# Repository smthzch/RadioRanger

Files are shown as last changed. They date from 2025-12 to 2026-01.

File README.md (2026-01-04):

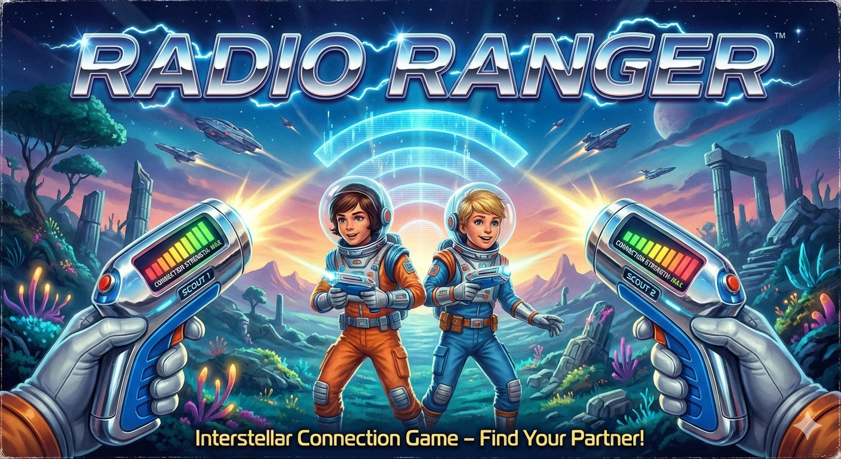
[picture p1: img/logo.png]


# Radio Ranger

Radio Ranger is a proximity sensing device. The LED meter increases in proportion to how close the two devices are to one another.

After the devices are turned on they will begin searching (single red light sweeping).
When one device discovers the other, it will display how close it is to the other device:

Far ← | Red | Yellow | Green | → Close

## Games

    • Blood Hound
        ◦ Hide one device and search with it with the other
    • Radio Tag
        ◦ Tag if green
    • Marco Polo
    • Use your imagination

## Battery Charge

Flashing indicates battery level 
    • No Flash = Charged
    • Slow Flash = Battery Low
    • Fast Flash = Charge Immediately

To charge plug in a usb-c cable to a standard 5v receptacle. 
The device must be turned ON in order to charge.

## Parts

- [XIAO ESP32C3](https://wiki.seeedstudio.com/XIAO_ESP32C3_Getting_Started/)
- [Adafruit LEDBAR](https://www.adafruit.com/product/1721)
- switch/battery

## XIAO ESP32C3 PINOUT

```
BATT(+/-)-|A0  USB  5V|-
         -|D1      GND|-LED(G)
         -|D2      3V3|-LED(VCC)
         -|D3      D10|-
LED(SDA) -|D4       D9|-
LED(SCL) -|D5       D8|-
         -|D6       D7|-
```

Pin A0 is connected to the positive and negative battery pads via 220K resistors for the battery voltage reading.
The battery is connected to the ESP32 battery pads via the switch.



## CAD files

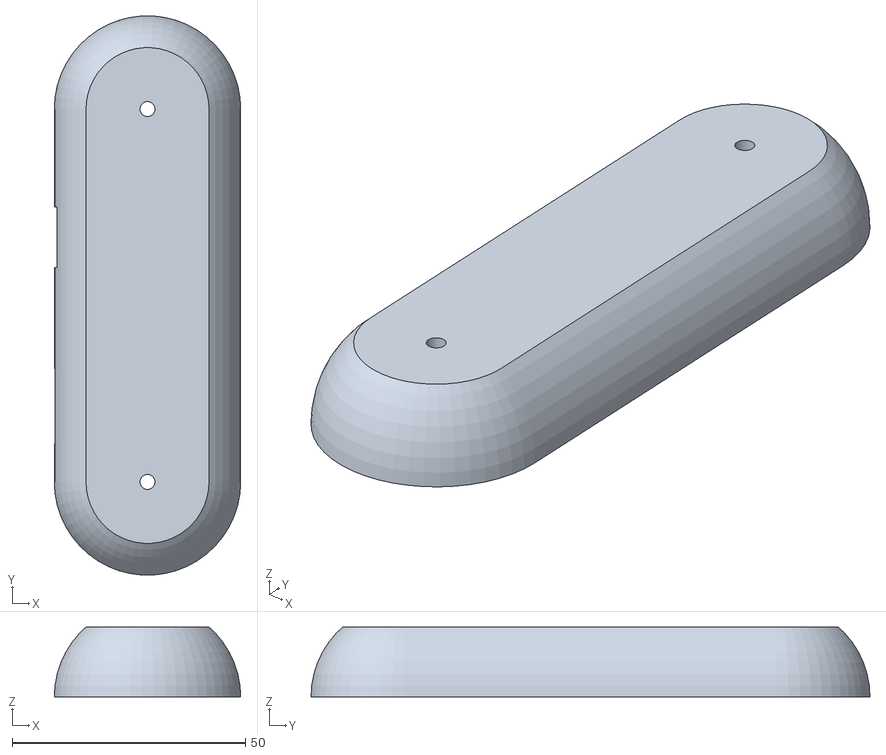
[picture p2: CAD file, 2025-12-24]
scad/radioranger_mini_top.stl
40.0 x 119.9 x 15.0

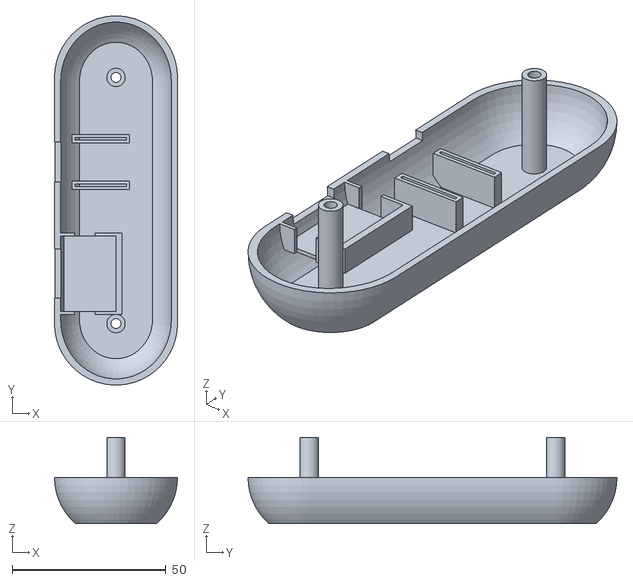
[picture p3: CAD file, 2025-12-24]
scad/radioranger_mini_bottom.stl
40.0 x 119.9 x 28.0

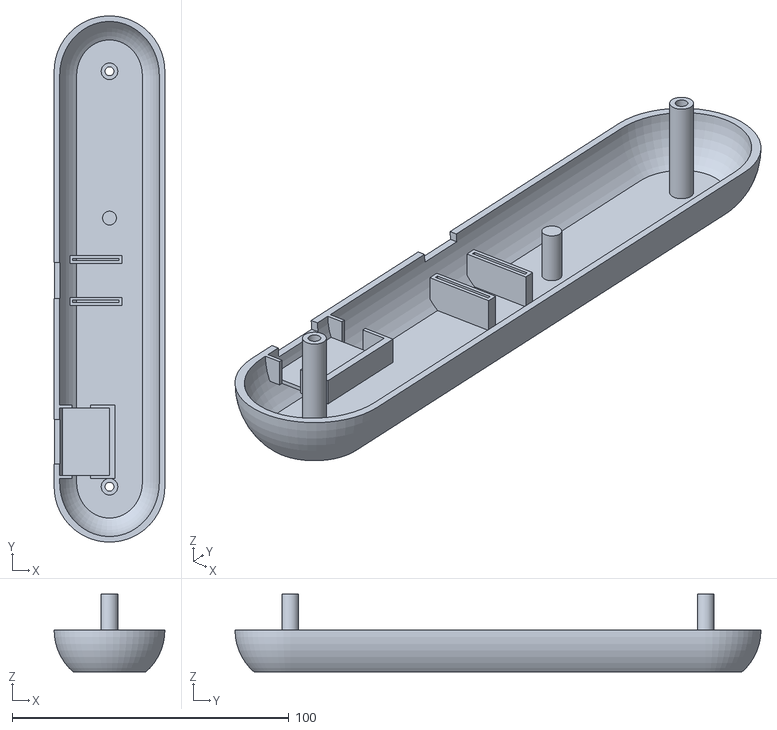
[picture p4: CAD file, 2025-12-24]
scad/radioranger_bottom.stl
40.0 x 189.9 x 28.0

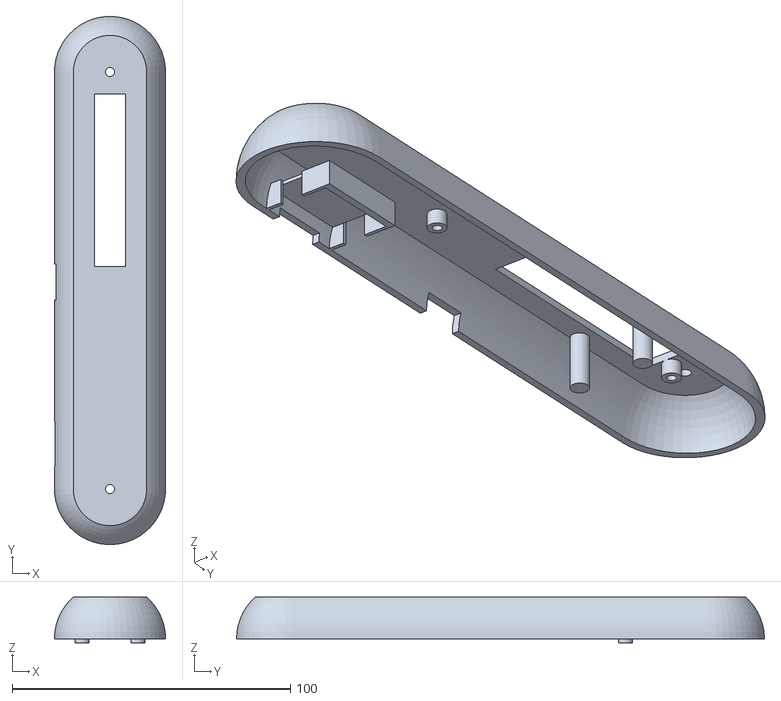
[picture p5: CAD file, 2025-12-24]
scad/radioranger_top.stl
40.0 x 189.9 x 16.5

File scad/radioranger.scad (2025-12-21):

$fn=50;



// screen hole
screen_l=62;
screen_w=11;
// switch holder
switch_l=26.5;
switch_d=20;
switch_h=13.5;
switch_t=1;
// enclosure
length=150; //150 //40
width=40;
wall_thickness=4;

//  ESP32 holder
module pinhole(w, d, h, o, do){
    difference(){
        translate([-o/2, -o/2, 0]) cube([w+o, d+do+o, h]);
        cube([w, d + do, h]);
    };
};

module esp_holder(){
    w=16.8;
    d=0.65;
    h=9;
    o=2;
    do = 0.2;
    
    pinhole(w, d, h, o, do);
    translate([0, 15.78 - d, 0]) pinhole(w, d, h, o, do);
}

module switch(){
    difference(){
        // switch body
        cube([switch_d, switch_l, switch_h]);
        // hollow
        translate([0, switch_t, switch_t])
        cube([
            switch_d-2*switch_t, 
            switch_l-2*switch_t, 
            switch_h-2*switch_t
        ]);
        // wire holes
        translate([switch_h/3, 0, 0])
        cube([switch_d/3, 1, switch_h]);
        // wire holes
        translate([switch_h/3, switch_l-switch_t, 0])
        cube([switch_d/3, 1, switch_h]);
    }
}

// enclosure
module shell(){   
    r=width/2;
    difference(){
        //main body
        union(){
            //center mass
            rotate([-90,0,0])
            cylinder(h=length,r=r);
            // end lobe 1
            sphere(r);
            // end lobe 2
            translate([0, length, 0])
            sphere(r);
        }
        // cutoff top
        translate([-r, -r, r - r/4])
        cube([2*r, length+2*r, 2*r]);
        // cutoff bottom
        translate([-r, -r, -3*r + r/4])
        cube([2*r, length+2*r, 2*r]);
    }
}

module hollow_shell(){
    difference(){
        // scale from origin so need to translate everything to be centered
        translate([0,length/2,0]) // return to original position
        difference(){
            translate([0, -length/2, 0]) // center it
            shell();
            //hollow it
            scale([
                1 - (wall_thickness / width), 
                1 - (wall_thickness / (length+width)), 
                1 - (wall_thickness / (3*width/4))
            ])
            translate([0, -length/2, 0]) // center it before scale
            shell();
        }
        // mounting hole
        translate([0, 0, -width/2])
        cylinder(h=width, d=3.2);
        // mounting hole
        translate([0, length, -width/2])
        cylinder(h=width, d=3.2);       
    }
    // internal components
    // switch
    translate([-width/2+switch_t+wall_thickness/2-1, 3, -switch_h/2])
    switch();
    //esp holder
    translate([-width/3, switch_l + 40, -width/3])
    esp_holder();
}

module enclosure(section){
    if(section=="top"){
        difference(){
            //shell
            hollow_shell();
            //remove bottom
            translate([-width/2, -width/2, -width])
            cube([width, length+width, width]);
            // screen hole
            translate([
                -screen_w/2, 
                length - screen_l - 3 - 5, 
                width/2 - width/8 -wall_thickness
            ])
            cube([screen_w, screen_l, wall_thickness]);
            // switch hole
            hole_l=16;
            hole_h=5;
            translate([-width/2, 26.5/2 - hole_l/2 + 3, -hole_h/2])
            cube([wall_thickness, hole_l, hole_h]);
            // usb hole
            translate([-width/2,switch_l+40+1.5,0])
            cube([wall_thickness, 13, 5]);
        }
        // screen mounting holes
        translate([0, length-3-2.5, 3*width/8-wall_thickness/2-4])
        difference(){
            cylinder(h=4, d=5);
            cylinder(h=4, d=2.5);
        }
        // screen mounting holes
        translate([0, length-3-2.5-95.25, 3*width/8-wall_thickness/2-4])
        difference(){
            cylinder(h=4, d=5);
            cylinder(h=4, d=2.5);
        }
        // battery holder
        buf=1.5;
        translate([10,120,-buf])
        cylinder(h=(3*width/8-wall_thickness/2)+buf, d=5);
        // battery holder
        translate([-10,120,-buf])
        cylinder(h=(3*width/8-wall_thickness/2)+buf, d=5);
    }if(section=="bottom"){
        difference(){
            //shell
            hollow_shell();
            //remove top
            translate([-width/2, -width/2, 0])
            cube([width, length+width, width]);
            // switch hole
            hole_l=16;
            hole_h=5;
            translate([-width/2, 26.5/2 - hole_l/2 + 3, -hole_h/2])
            cube([wall_thickness, hole_l, hole_h]);
            // usb hole
            translate([-width/2,switch_l+40+1.5,-2.2])
            cube([wall_thickness, 13, 2.2]);
        }
        // add mounting holes
        //mounting hole 1
        translate([0, 0, -3*width/8 + wall_thickness/2])
        difference(){
            cylinder(h=3*width/4 - wall_thickness, d=6);
            cylinder(h=3*width/4 - wall_thickness, d=3.2);
        }
        //mounting hole 2
        translate([0, length, -3*width/8 + wall_thickness/2])
        difference(){
            cylinder(h=3*width/4 - wall_thickness, d=6);
            cylinder(h=3*width/4 - wall_thickness, d=3.2);
        }
        // battery holder
        buf=1.5;
        translate([0,length-50-3,-3*width/8+wall_thickness/2])
        cylinder(h=(3*width/8-wall_thickness/2), d=5);
    }
}
section="bottom";
enclosure(section=section);
//enclosure(section="top");

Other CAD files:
scad/radioranger_mini.scad

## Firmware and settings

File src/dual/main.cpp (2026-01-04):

/* 
===========================================================
            Radio Ranger

This device connects to an equivalent device via bluetooth,
reads the signal strength and updates a LED bar visualizing
the relative strength.
===========================================================
            Pin Layout

BATT(+/-)-|A0  USB  5V|-
         -|D1      GND|-LED(G)
         -|D2      3V3|-LED(VCC)
         -|D3      D10|-
LED(SDA) -|D4       D9|-
LED(SCL) -|D5       D8|-
         -|D6       D7|-
*/

#if defined(RADIO)
  const char* MY_DEVICE_NAME = "RADIO";
  static const char* OTHER_DEVICE_MAC = "40:4c:ca:3c:f1:2a";
#elif defined(RANGER)
  const char* MY_DEVICE_NAME = "RANGER";
  static const char* OTHER_DEVICE_MAC = "94:a9:90:69:e6:12";
#else
  #error "Please define RADIO or RANGER in build flags or at top of sketch"
#endif

#include <BLEDevice.h>
#include <BLEScan.h>
#include <BLEAdvertisedDevice.h>
#include "Adafruit_LEDBackpack.h"
#include "battery.h"
#include "ledbar.h"

Adafruit_24bargraph  bar = Adafruit_24bargraph();

static BLEAddress targetAddr(OTHER_DEVICE_MAC);

BLEScan* pBLEScan = nullptr;
unsigned long previousMillis = 0;
const long interval = 500;  // Scan + update every 1.1 seconds
int no_contact = 1;
float min_rssi = -100;
float smooth_rssi = min_rssi;
float alpha = 0.2;


class MyAdvertisedDeviceCallbacks : public BLEAdvertisedDeviceCallbacks {
  void onResult(BLEAdvertisedDevice advertisedDevice) {
    if (advertisedDevice.getAddress().equals(targetAddr)) {
      smooth_rssi = alpha * (float)advertisedDevice.getRSSI() + (1 - alpha)* smooth_rssi;
      no_contact = 0;
    }
  }
};

// Dummy callback for asynchronous scanning
void onScanComplete(BLEScanResults results) {}

void setup() {
  Wire.setClock(100000);
  initBar(bar);

  pinMode(A0, INPUT); // ADC for battery voltage
  Serial.begin(9600);
  delay(1500);  // For XIAO USB CDC

  // BLE init
  BLEDevice::init(MY_DEVICE_NAME);

  // Start advertising (peripheral mode)
  BLEAdvertising* pAdvertising = BLEDevice::getAdvertising();
  pAdvertising->setScanResponse(true);
  pAdvertising->setMinPreferred(0x06);  // Helps with compatibility
  pAdvertising->start();
  Serial.println("Advertising started");
  
  // Setup scanner (central mode)
  pBLEScan = BLEDevice::getScan();
  pBLEScan->setAdvertisedDeviceCallbacks(new MyAdvertisedDeviceCallbacks());
  pBLEScan->setActiveScan(false);  // Passive scan saves power
  //pBLEScan->setInterval(200);
  //pBLEScan->setWindow(100);
  pBLEScan->start(0, &onScanComplete, false);
  Serial.println("Continuous scanning started");

  // Print BLE MAC address for client to use
  Serial.print("BLE Address: ");
  Serial.println(BLEDevice::getAddress().toString().c_str());
  Serial.println("Waiting for connection...");
  
}

void loop() {
  unsigned long currentMillis = millis();
  if (currentMillis - previousMillis >= interval) {
    previousMillis = currentMillis;
    pBLEScan->stop();

    no_contact++;
    if (no_contact > 4){
      smooth_rssi = min_rssi;
    }

    // Serial output
    Serial.print("RSSI: ");
    Serial.print(smooth_rssi);
    Serial.println(" dBm");

    // LED output
    setBar(bar, smooth_rssi);

    float Vbattf = batteryVoltage(A0);
    Serial.println(Vbattf, 3);
    if (Vbattf > 3.6){
      bar.blinkRate(0);
    }else if(Vbattf > 3.4){
      bar.blinkRate(2);
    }else{
      bar.blinkRate(1);
    }

    pBLEScan->start(0, &onScanComplete, false);
  }
}

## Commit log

2025-12-21 halfway radio/ranger
    [radioranger.scad, radioranger_bottom.stl, radioranger_top.stl]
2025-12-21 updaate scad location
    [radioranger_bottom.stl, radioranger_top.stl]
2025-12-21 fix ledbar func signature (receive reference)
2025-12-21 move, combine, everything
    [radioranger.scad, radioranger_bottom.stl, radioranger_top.stl]
2025-12-21 add back in scad stuff
    [radioranger.scad, radioranger_bottom.stl, radioranger_top.stl]
2025-12-21 fix led dynamic range, add no signal sweep
2025-12-21 fix ranger env flag
    [main.cpp]
2025-12-24 add a mono ranger
    [radioranger_bottom.stl, radioranger_mini.scad, radioranger_mini_bottom.stl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]
2025-12-24 pin layount mono radio
